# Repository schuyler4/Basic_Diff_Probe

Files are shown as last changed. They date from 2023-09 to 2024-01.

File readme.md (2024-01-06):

<h1> 
Basic Diff Probe 
</h1>
I need a differential probe, but I don't need particularly good specs. I don't need very high bandwidth or voltage. This is my solution. 

There are two revisions. The second revision is the same circuit board and circuit as the first revision. The only difference is a compensation
capacitor added in the feedback loop of the split supply buffer to get rid of some oscillation I was seeing.
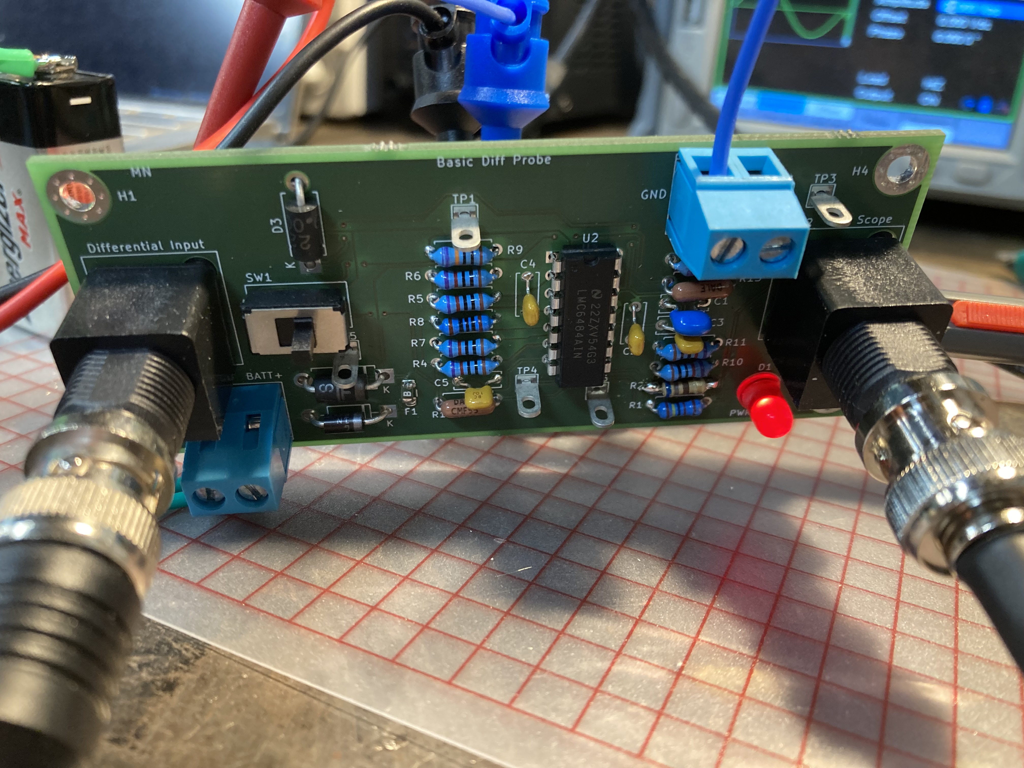
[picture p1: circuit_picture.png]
Circuit Picture


<h3> Specs </h3>
<ul>
<li> Power Supply: 9V Battery </li>
<li> Bandwidth: 20kHz (1x) / 200Hz (10x) </li>
<li> Offset < 2mV </li>
<li> Maximum Differential Input 10x (1x): 50V (5V) </li>
<li> Minimum Differential Input 10x (1x): -50V (-5V) </li>
<li> Maximum Single Ended Input 10x (1x): 25V (2.5V) </li>
<li> Minimum Differential Input 10x (1x): -25V (-2.5V) </li>
<li> Attenuation Options: 
<ul>
    <li> 10X </li>
    <li> 1X </li>
</ul>
</li>
</ul>
<h3> Example </h3>
Here is an example measurement taken of a sweep from my curve tracer. The purple trace is from the diff probe and the yellow trace is regular single ended oscilloscope measurement.    

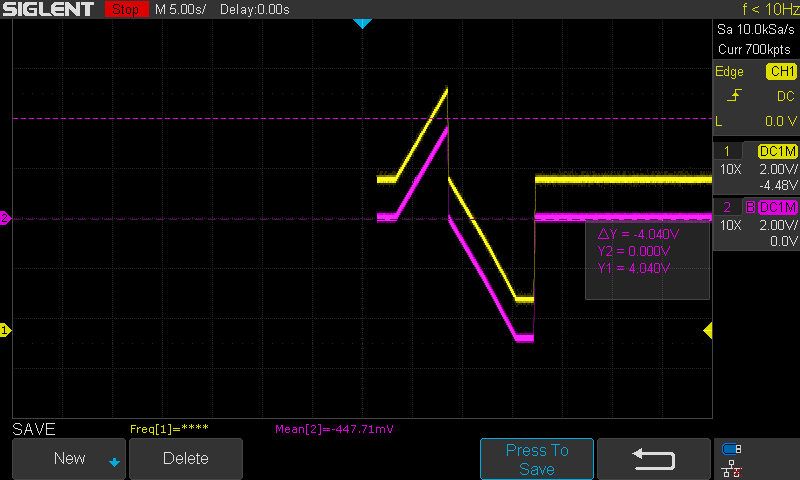
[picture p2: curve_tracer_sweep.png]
Trace


<h3> Possible Improvements </h3>
<ol>
<li> For some reason the bandwidth in 10x mode is very low. I'm not sure why this is. </li> 
<li> It is very hard to tell which mode the probe is in (10x or 1x) without looking at a known signal. </li>
</ol>
</p>

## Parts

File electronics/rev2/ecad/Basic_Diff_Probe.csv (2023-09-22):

Source: | C:\Users\marek\Documents\projects\Basic_Diff_Probe\ecad\Basic_Diff_Probe.kicad_sch
Date: | 9/8/2023 5:32:33 PM
Tool: | Eeschema 7.0.1
Generator: | C:\Program Files\KiCad\6.0\bin\scripting\plugins/bom_csv_grouped_by_value.py
Component Count: | 38
Individual Components:
Item | Qty | Reference(s) | Value | LibPart | Footprint | Datasheet
 |  | C1 | 10uF | Device:C | Capacitor_THT:C_Disc_D6.0mm_W2.5mm_P5.00mm | ~
 |  | C2 | 0.1uF | Device:C | Capacitor_THT:C_Disc_D6.0mm_W2.5mm_P5.00mm | ~
 |  | C3 | 0.1uF | Device:C | Capacitor_THT:C_Disc_D6.0mm_W2.5mm_P5.00mm | ~
 |  | C4 | 0.1uF | Device:C | Capacitor_THT:C_Disc_D6.0mm_W2.5mm_P5.00mm | ~
 |  | C5 | 10pF | Device:C | Capacitor_THT:C_Disc_D6.0mm_W2.5mm_P5.00mm | ~
 |  | D1 | WP7113ID | Device:LED | LED_THT:LED_D5.0mm | ~
 |  | D2 | SA10A | Device:D_Zener | Diode_THT:D_DO-15_P10.16mm_Horizontal | ~
 |  | D3 | SA9.0CA | Device:D_TVS | Diode_THT:D_DO-15_P10.16mm_Horizontal | ~
 |  | D4 | 1N5817 | Diode:1N5817 | Diode_THT:D_DO-41_SOD81_P10.16mm_Horizontal | http://www.vishay.com/docs/88525/1n5817.pdf
 |  | F1 | 100mA | Device:Fuse | Fuse:Fuse_1206_3216Metric_Pad1.42x1.75mm_HandSolder | ~
 |  | H1 | M3 | Mechanical:MountingHole_Pad | MountingHole:MountingHole_3.2mm_M3_Pad_Via | ~
 |  | H2 | M3 | Mechanical:MountingHole_Pad | MountingHole:MountingHole_3.2mm_M3_Pad_Via | ~
 |  | H3 | M3 | Mechanical:MountingHole_Pad | MountingHole:MountingHole_3.2mm_M3_Pad_Via | ~
 |  | H4 | M3 | Mechanical:MountingHole_Pad | MountingHole:MountingHole_3.2mm_M3_Pad_Via | ~
 |  | J1 | 9V Battery Input | Connector:Screw_Terminal_01x02 | TerminalBlock_Phoenix:TerminalBlock_Phoenix_MKDS-1,5-2-5.08_1x02_P5.08mm_Horizontal | ~
 |  | J2 | To Scope | Connector:Conn_Coaxial | Connector_Coaxial:BNC_Amphenol_031-5539_Vertical | ~
 |  | J3 | Differential Input | Connector:Conn_Coaxial | Connector_Coaxial:BNC_Amphenol_031-5539_Vertical | ~
 |  | R1 | 1.4k | Device:R_US | Resistor_THT:R_Axial_DIN0207_L6.3mm_D2.5mm_P7.62mm_Horizontal | ~
 |  | R2 | 0 | Device:R_US | Resistor_THT:R_Axial_DIN0207_L6.3mm_D2.5mm_P7.62mm_Horizontal | ~
 |  | R4 | 10k | Device:R_US | Resistor_THT:R_Axial_DIN0207_L6.3mm_D2.5mm_P7.62mm_Horizontal | ~
 |  | R5 | 10k | Device:R_US | Resistor_THT:R_Axial_DIN0207_L6.3mm_D2.5mm_P7.62mm_Horizontal | ~
 |  | R6 | 10k | Device:R_US | Resistor_THT:R_Axial_DIN0207_L6.3mm_D2.5mm_P7.62mm_Horizontal | ~
 |  | R7 | 10k | Device:R_US | Resistor_THT:R_Axial_DIN0207_L6.3mm_D2.5mm_P7.62mm_Horizontal | ~
 |  | R8 | 100 | Device:R_US | Resistor_THT:R_Axial_DIN0207_L6.3mm_D2.5mm_P7.62mm_Horizontal | ~
 |  | R9 | 100k | Device:R_US | Resistor_THT:R_Axial_DIN0207_L6.3mm_D2.5mm_P7.62mm_Horizontal | ~
 |  | R10 | 10k | Device:R_US | Resistor_THT:R_Axial_DIN0207_L6.3mm_D2.5mm_P7.62mm_Horizontal | ~
 |  | R11 | 10k | Device:R_US | Resistor_THT:R_Axial_DIN0207_L6.3mm_D2.5mm_P7.62mm_Horizontal | ~
 |  | R12 | 900k | Device:R_US | Resistor_THT:R_Axial_DIN0207_L6.3mm_D2.5mm_P7.62mm_Horizontal | ~
 |  | R13 | 900k | Device:R_US | Resistor_THT:R_Axial_DIN0207_L6.3mm_D2.5mm_P7.62mm_Horizontal | ~
 |  | R16 | 100k | Device:R_US | Resistor_THT:R_Axial_DIN0207_L6.3mm_D2.5mm_P7.62mm_Horizontal | ~
 |  | SW1 | EG2209A | Switch:SW_Push_DPDT | Diff_Probe_Parts:SW_EG2209A | ~
 |  | TP1 | TestPoint | Connector:TestPoint | TestPoint:TestPoint_Keystone_5000-5004_Miniature | ~
 |  | TP2 | TestPoint | Connector:TestPoint | TestPoint:TestPoint_Keystone_5000-5004_Miniature | ~
 |  | TP3 | TestPoint | Connector:TestPoint | TestPoint:TestPoint_Keystone_5000-5004_Miniature | ~
 |  | TP4 | TestPoint | Connector:TestPoint | TestPoint:TestPoint_Keystone_5000-5004_Miniature | ~
 |  | TP5 | TestPoint | Connector:TestPoint | TestPoint:TestPoint_Keystone_5000-5004_Miniature | ~
 |  | TP6 | TestPoint | Connector:TestPoint | TestPoint:TestPoint_Keystone_5000-5004_Miniature | ~
 |  | U2 | LMC6484AIN | Device:Opamp_Quad | Package_DIP:DIP-14_W7.62mm | ~
Collated Components:
Item | Qty | Reference(s) | Value | LibPart | Footprint | Datasheet
1 | 1 | C1 | 10uF | Device:C | Capacitor_THT:C_Disc_D6.0mm_W2.5mm_P5.00mm | ~
2 | 3 | C2, C3, C4 | 0.1uF | Device:C | Capacitor_THT:C_Disc_D6.0mm_W2.5mm_P5.00mm | ~
3 | 1 | C5 | 10pF | Device:C | Capacitor_THT:C_Disc_D6.0mm_W2.5mm_P5.00mm | ~
4 | 1 | D1 | WP7113ID | Device:LED | LED_THT:LED_D5.0mm | ~
5 | 1 | D2 | SA10A | Device:D_Zener | Diode_THT:D_DO-15_P10.16mm_Horizontal | ~
6 | 1 | D3 | SA9.0CA | Device:D_TVS | Diode_THT:D_DO-15_P10.16mm_Horizontal | ~
7 | 1 | D4 | 1N5817 | Diode:1N5817 | Diode_THT:D_DO-41_SOD81_P10.16mm_Horizontal | http://www.vishay.com/docs/88525/1n5817.pdf
8 | 1 | F1 | 100mA | Device:Fuse | Fuse:Fuse_1206_3216Metric_Pad1.42x1.75mm_HandSolder | ~
9 | 4 | H1, H2, H3, H4 | M3 | Mechanical:MountingHole_Pad | MountingHole:MountingHole_3.2mm_M3_Pad_Via | ~
10 | 1 | J1 | 9V Battery Input | Connector:Screw_Terminal_01x02 | TerminalBlock_Phoenix:TerminalBlock_Phoenix_MKDS-1,5-2-5.08_1x02_P5.08mm_Horizontal | ~
11 | 1 | J2 | To Scope | Connector:Conn_Coaxial | Connector_Coaxial:BNC_Amphenol_031-5539_Vertical | ~
12 | 1 | J3 | Differential Input | Connector:Conn_Coaxial | Connector_Coaxial:BNC_Amphenol_031-5539_Vertical | ~
13 | 1 | R1 | 1.4k | Device:R_US | Resistor_THT:R_Axial_DIN0207_L6.3mm_D2.5mm_P7.62mm_Horizontal | ~
14 | 1 | R2 | 0 | Device:R_US | Resistor_THT:R_Axial_DIN0207_L6.3mm_D2.5mm_P7.62mm_Horizontal | ~
15 | 6 | R4, R5, R6, R7, R10, R11 | 10k | Device:R_US | Resistor_THT:R_Axial_DIN0207_L6.3mm_D2.5mm_P7.62mm_Horizontal | ~
16 | 1 | R8 | 100 | Device:R_US | Resistor_THT:R_Axial_DIN0207_L6.3mm_D2.5mm_P7.62mm_Horizontal | ~
17 | 2 | R9, R16 | 100k | Device:R_US | Resistor_THT:R_Axial_DIN0207_L6.3mm_D2.5mm_P7.62mm_Horizontal | ~
18 | 2 | R12, R13 | 900k | Device:R_US | Resistor_THT:R_Axial_DIN0207_L6.3mm_D2.5mm_P7.62mm_Horizontal | ~
19 | 1 | SW1 | EG2209A | Switch:SW_Push_DPDT | Diff_Probe_Parts:SW_EG2209A | ~
20 | 6 | TP1, TP2, TP3, TP4, TP5, TP6 | TestPoint | Connector:TestPoint | TestPoint:TestPoint_Keystone_5000-5004_Miniature | ~
21 | 1 | U2 | LMC6484AIN | Device:Opamp_Quad | Package_DIP:DIP-14_W7.62mm | ~

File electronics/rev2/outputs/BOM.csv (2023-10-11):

Item | Qty | Reference(s) | Value | Part # | Distributor | Distributor Part # | Unit Price | Price | Carted
1 | 1 | C1 | 10uF | FG26X7R1E106KRT06 | DIGIKEY | 445-173437-1-ND | 0.67 | 0.67 | T
2 | 3 | C2, C3, C4 | 0.1uF | K104K10X7RF5UH5 | DIGIKEY | BC2665CT-ND | 0.23 | 0.69 | T
3 | 1 | C5 | 10pF | K100J15C0GF5TH5 | DIGIKEY | BC1030CT-ND | 0.27 | 0.27 | T
4 | 1 | D1 | WP7113ID | WP7113ID | DIGIKEY | 754-1264-ND | 0.1 | 0.1 | T
5 | 1 | D2 | SA10A | SA10A | DIGIKEY | SA10ALFCT-ND | 0.44 | 0.44 | T
6 | 1 | D3 | SA9.0CA | SA9.0CA | DIGIKEY | 18-SA9.0CACT-ND | 0.49 | 0.49 | T
7 | 1 | D4 | 1N5817 | 1N5817 | DIGIKEY | 497-4547-1-ND | 0.44 | 0.44 | T
8 | 1 | F1 | 100mA | 0466.125NR | DIGIKEY | F1450CT-ND | 0.91 | 0.91 | T
9 | 1 | J1 | 9V Battery Input | TB004-508-02BE | DIGIKEY | 102-6179-ND | 0.71 | 0.71 | T
10 | 1 | J2 | To Scope | 031-5539 | DIGIKEY | ARF2045-ND | 7.35 | 7.35 | T
11 | 1 | J3 | Differential Input | 031-5539 | DIGIKEY | ARF2045-ND | 7.35 | 7.35 | T
12 | 1 | R1 | 1.4k | MFR-25FBF52-1K4 | DIGIKEY | 1.40KXBK-ND | 0.1 | 0.1 | T
13 | 1 | R2 | 680 | CF14JT680RCT-ND | DIGIKEY | CF14JT680RCT-ND | 0.1 | 0.1 | T
14 | 6 | R4, R5, R6, R7, R10, R11 | 10k | YR1B10KCC | DIGIKEY | A105970CT-ND | 0.63 | 3.78 | T
15 | 1 | R8 | 100 | MFR-25FBF52-100R | DIGIKEY | 100XBK-ND | 0.1 | 0.1 | T
16 | 2 | R9, R16 | 100k | YR1B100KCC | DIGIKEY | A105968CT-ND | 0.63 | 1.26 | T
17 | 2 | R12, R13 | 900k | CMF55900K00BEBF | DIGIKEY | CMF55900K00BEBF-ND | 2.44 | 4.88 | T
18 | 1 | SW1 | EG2209A | EG2209A | DIGIKEY | EG1908-ND | 1.18 | 1.18 | T
19 | 6 | TP1, TP2, TP3, TP4, TP5, TP6 | TestPoint | 4952 | DIGIKEY | 36-4952-ND | 0.26 | 1.56 | T
20 | 1 | U2 | LMC6484AIN | LMC6484AIN/NOPB | DIGIKEY | LMC6484AIN/NOPB-ND | 3.18 | 3.18 | T
total: |  |  |  |  |  |  |  | 35.61

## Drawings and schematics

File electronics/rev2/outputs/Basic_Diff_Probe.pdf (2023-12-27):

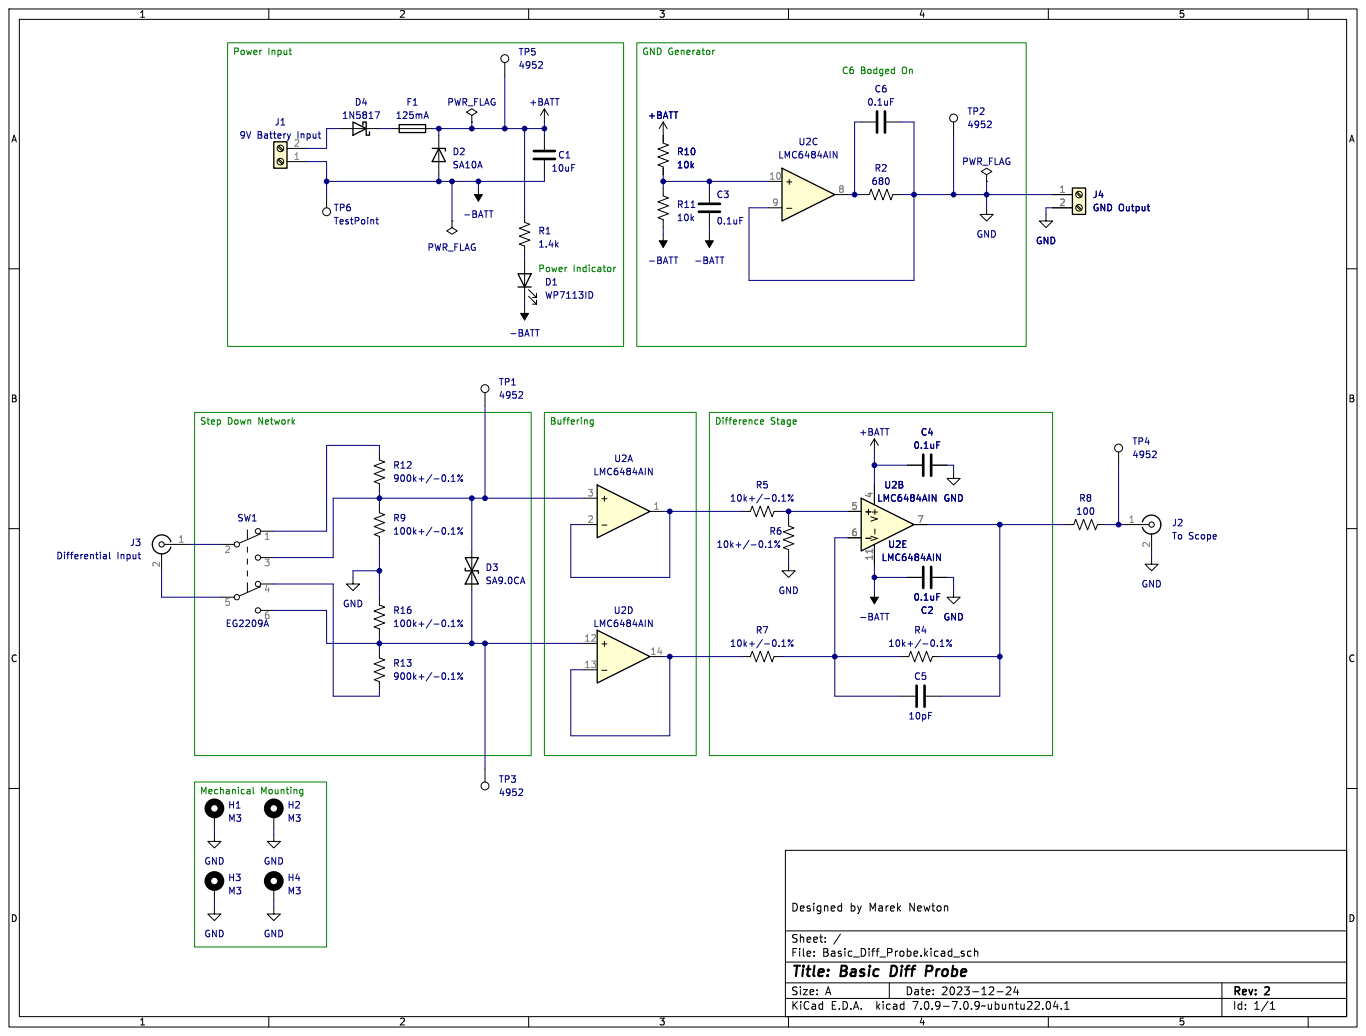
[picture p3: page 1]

Id: 1/1 Title: Basic Diff Probe

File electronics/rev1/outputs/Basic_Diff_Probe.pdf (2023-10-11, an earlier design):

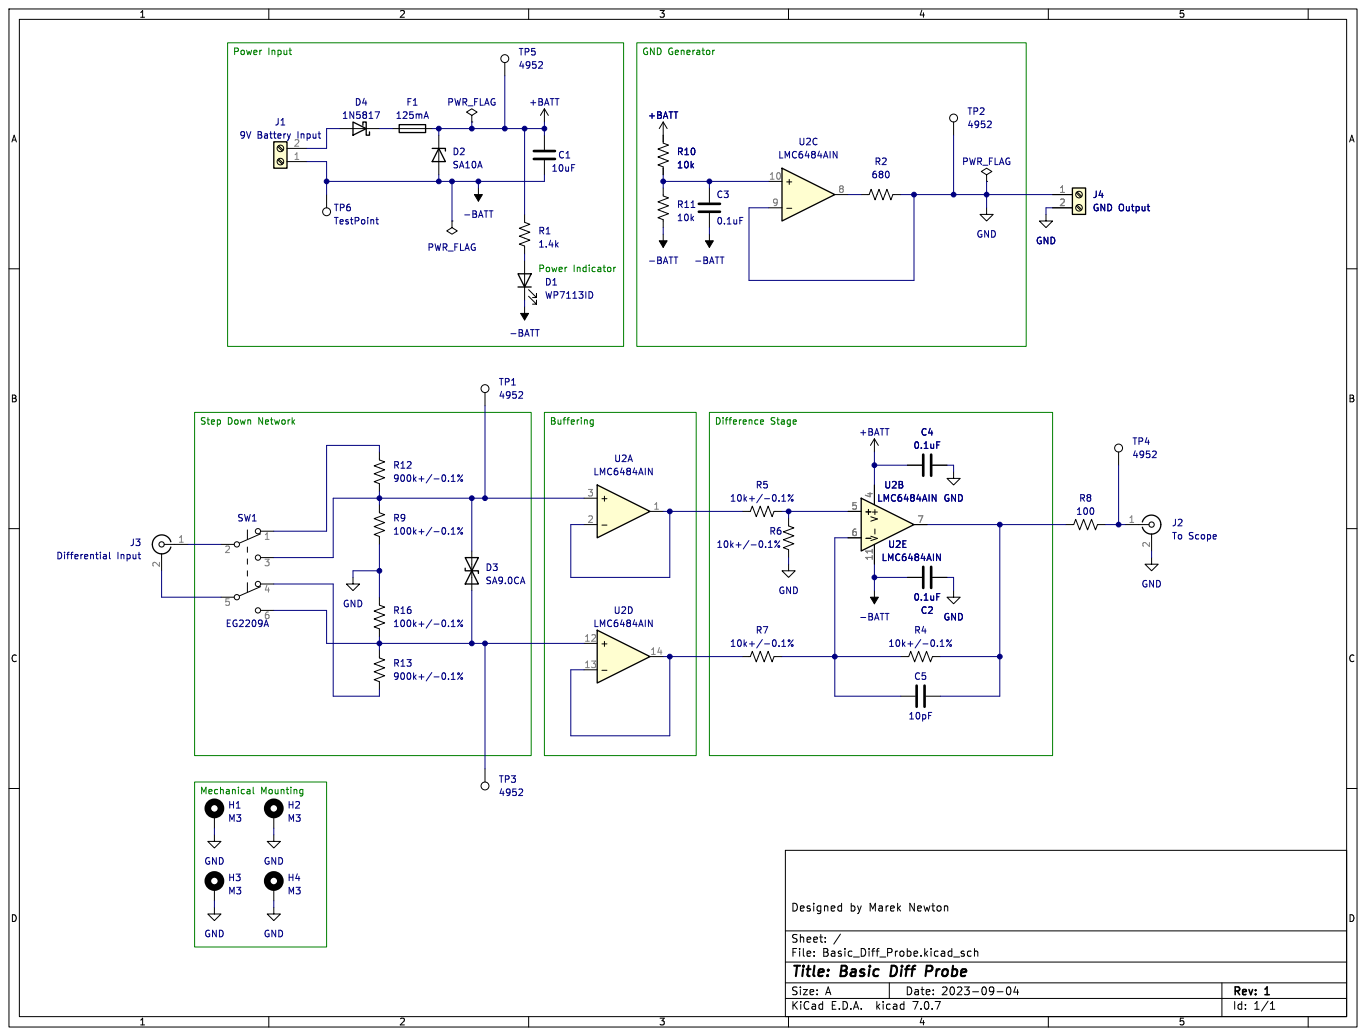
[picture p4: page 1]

Power Indicator Power Input

Id: 1/1 Title: Basic Diff Probe

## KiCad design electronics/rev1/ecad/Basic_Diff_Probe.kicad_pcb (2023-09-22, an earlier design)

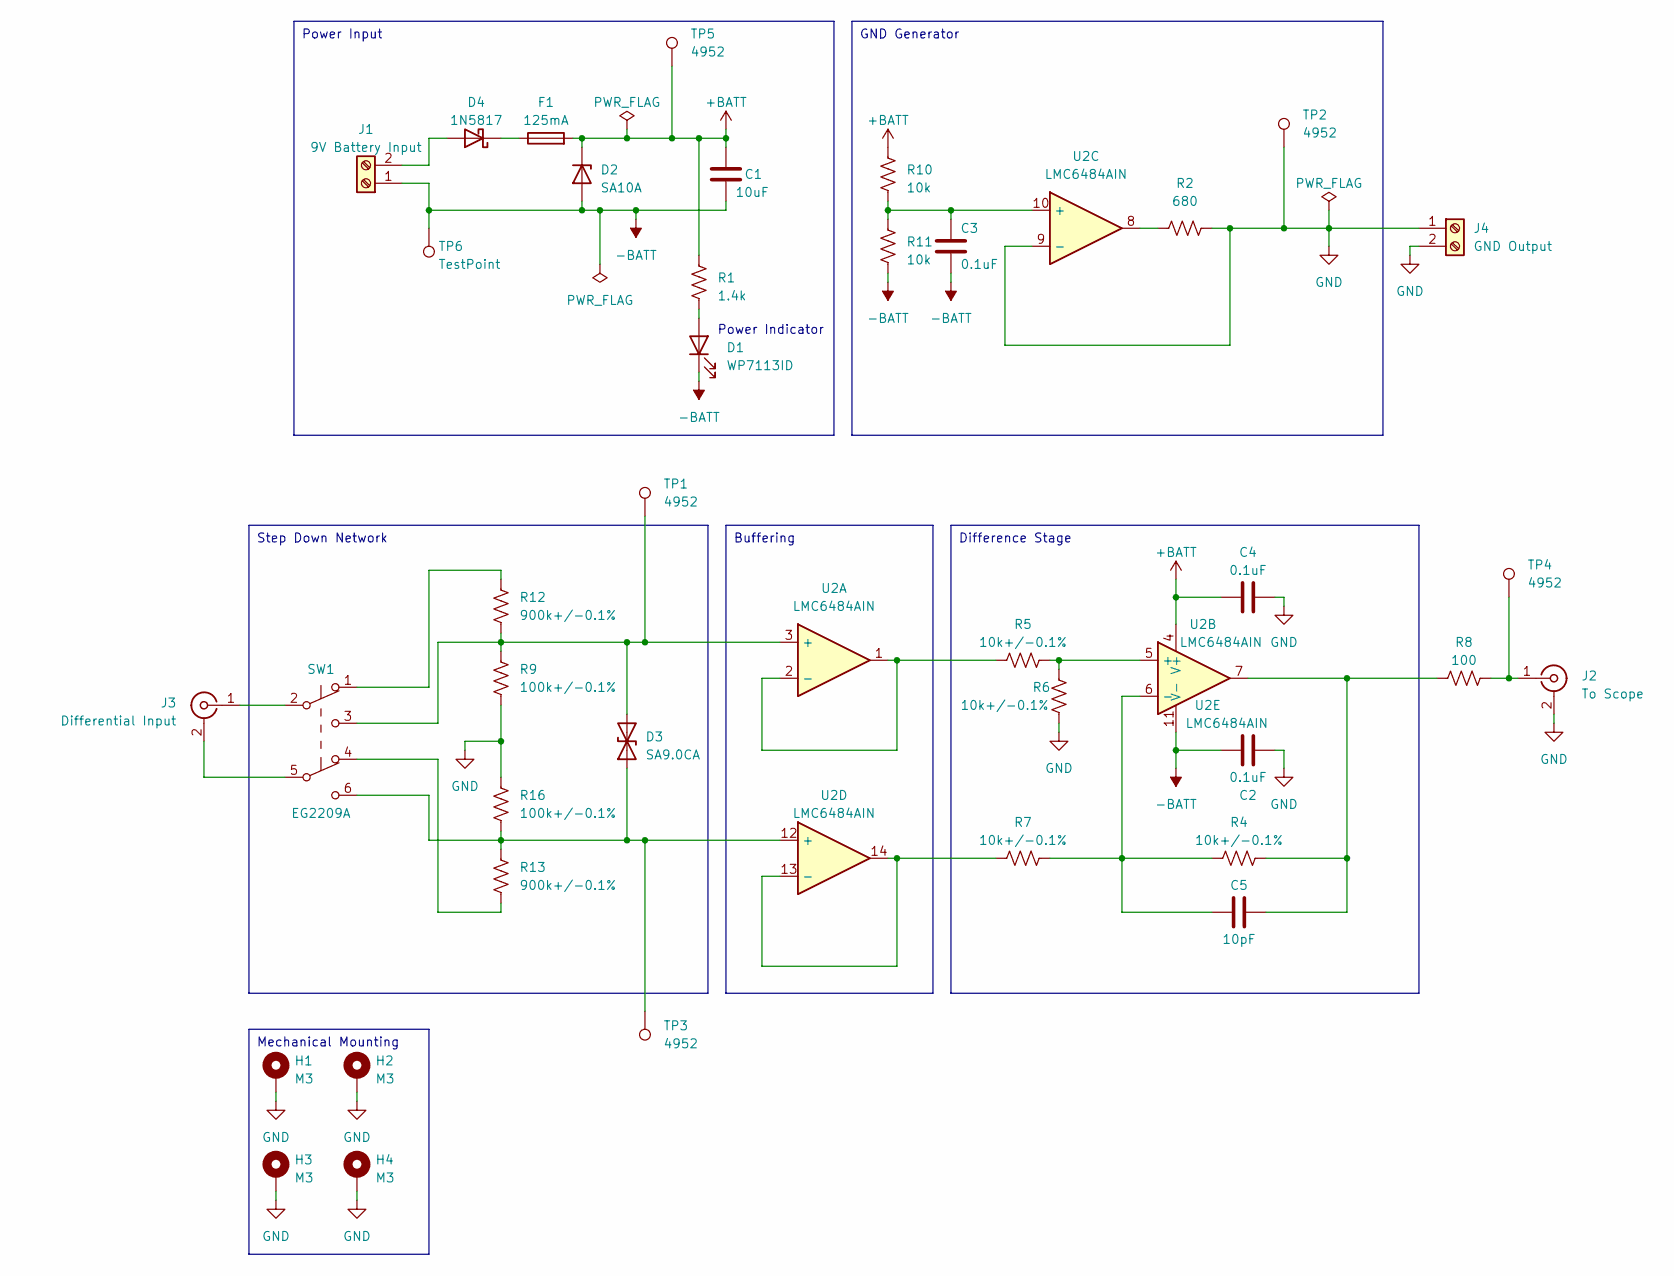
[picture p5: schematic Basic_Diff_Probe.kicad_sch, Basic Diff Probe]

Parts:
C1: 10uF; C_Disc_D6.0mm_W2.5mm_P5.00mm
C2, C3, C4: 0.1uF; C_Disc_D6.0mm_W2.5mm_P5.00mm
C5: 10pF; C_Disc_D6.0mm_W2.5mm_P5.00mm
D1: WP7113ID; LED_D5.0mm
D2: SA10A; D_DO-15_P10.16mm_Horizontal
D3: SA9.0CA; D_DO-15_P10.16mm_Horizontal
D4: 1N5817; D_DO-41_SOD81_P10.16mm_Horizontal
F1: 125mA; Fuse_1206_3216Metric_Pad1.42x1.75mm_HandSolder
H1, H2, H3, H4: M3; MountingHole_3.2mm_M3_Pad_Via
J1: 9V Battery Input; TerminalBlock_Phoenix_MKDS-1,5-2-5.08_1x02_P5.08mm_Horizont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
J2: To Scope; BNC_Amphenol_031-5539_Vertical
J3: Differential Input; BNC_Amphenol_031-5539_Vertical
J4: GND Output; TerminalBlock_Phoenix_MKDS-1,5-2-5.08_1x02_P5.08mm_Horizont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
R1: 1.4k; R_Axial_DIN0207_L6.3mm_D2.5mm_P7.62mm_Horizontal
R2: 680; R_Axial_DIN0207_L6.3mm_D2.5mm_P7.62mm_Horizontal
R4, R5, R6, R7: 10k+/-0.1%; R_Axial_DIN0207_L6.3mm_D2.5mm_P7.62mm_Horizontal
R8: 100; R_Axial_DIN0207_L6.3mm_D2.5mm_P7.62mm_Horizontal
R9, R16: 100k+/-0.1%; R_Axial_DIN0207_L6.3mm_D2.5mm_P7.62mm_Horizontal
R10, R11: 10k; R_Axial_DIN0207_L6.3mm_D2.5mm_P7.62mm_Horizontal
R12, R13: 900k+/-0.1%; R_Axial_DIN0207_L6.3mm_D2.5mm_P7.62mm_Horizontal
SW1: EG2209A; SW_EG2209A
TP1, TP2, TP3, TP4, TP5: 4952; TestPoint_THTPad_2.5x2.5mm_Drill1.2mm
TP6: TestPoint; TestPoint_THTPad_2.5x2.5mm_Drill1.2mm
U2: LMC6484AIN; DIP-14_W7.62mm

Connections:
+BATT: C1.1, C4.2, D2.1 (K), F1.2, R1.1, R10.1, TP5.1, U2.4 (V+)
-BATT: C1.2, C2.2, C3.2, D1.1 (K), D2.2 (A), J1.1, R11.2, TP6.1, U2.11 (V-)
GND: C2.1, C4.1, H1.1, H2.1, H3.1, H4.1, J2.2 (Ext), J4.1, J4.2, R2.2, R6.2, R9.2, R16.1, TP2.1, U2.9 (-)
unnamed: C5.2, R4.2, R8.1, U2.7
unnamed: D1.2 (A), R1.2
unnamed: D3.1 (A1), R13.1, R16.2, SW1.6 (C), TP3.1, U2.12 (+)
unnamed: D3.2 (A2), R9.1, R12.2, SW1.3 (C), TP1.1, U2.3 (+)
unnamed: D4.2 (A), J1.2
unnamed: D4.1 (K), F1.1
unnamed: J2.1 (In), R8.2, TP4.1
unnamed: J3.2 (Ext), SW1.5 (B)
unnamed: J3.1 (In), SW1.2 (B)
unnamed: R2.1, U2.8
unnamed: R12.1, SW1.1 (A)
unnamed: R13.2, SW1.4 (A)
unnamed: R5.1, U2.1, U2.2 (-)
unnamed: R5.2, R6.1, U2.5 (+)
unnamed: C5.1, R4.1, R7.2, U2.6 (-)
unnamed: C3.1, R10.2, R11.1, U2.10 (+)
unnamed: R7.1, U2.13 (-), U2.14

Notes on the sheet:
Buffering
GND Generator
Power Input
Step Down Network
Mechanical Mounting
Difference Stage
Power Indicator

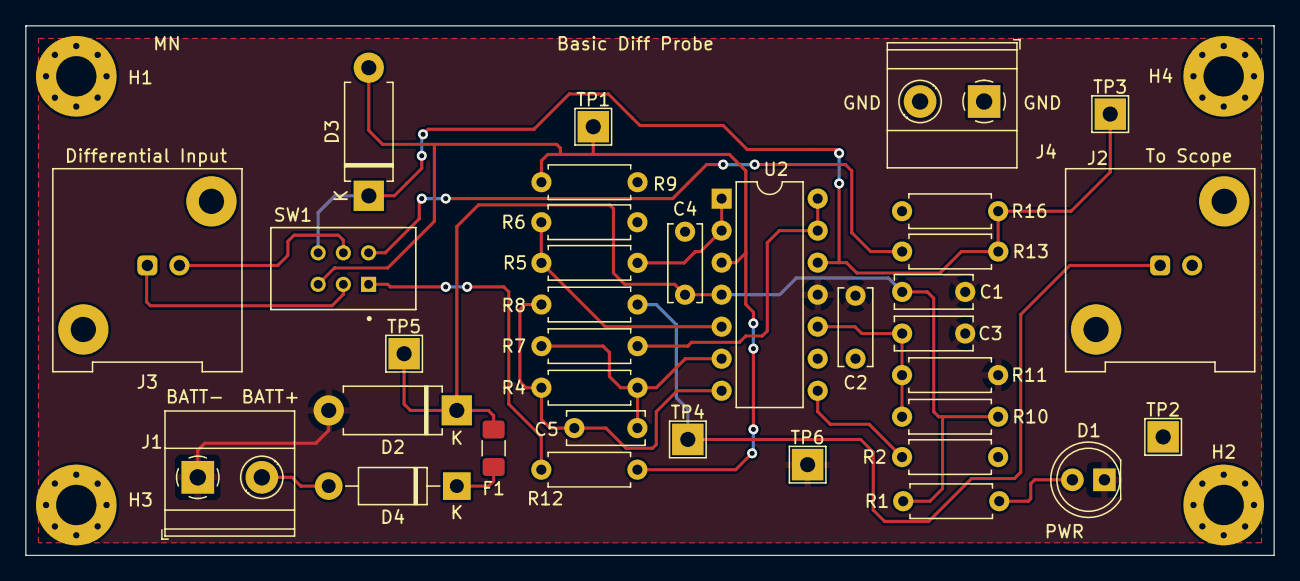
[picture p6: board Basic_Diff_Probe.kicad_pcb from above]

Board: 2 copper layers, 99.0 x 42.0 mm, 39 parts (0 on the bottom side), 20 nets.

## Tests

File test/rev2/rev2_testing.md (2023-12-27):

<h3>Accuracy Test</h3>
<p>
<b>Procedure:</b> Connect a function generator with a sine wave that has a frequency of 20kHz, and a peak voltage of 2.5Vp/10Vp. Connect the sine wave across the differential probe and a regular calibrated single ended scope probe. Make sure the diff probe ground is also connected. Look at both traces on the oscilloscope. Repeat for both 10x mode and 1x mode. If the diff probe sine wave is significantly distorted or attenuated decrees the frequency. This will find the bandwidth of the diff probe.
</p>

<b>Results:</b> The 1x trace is shown below:

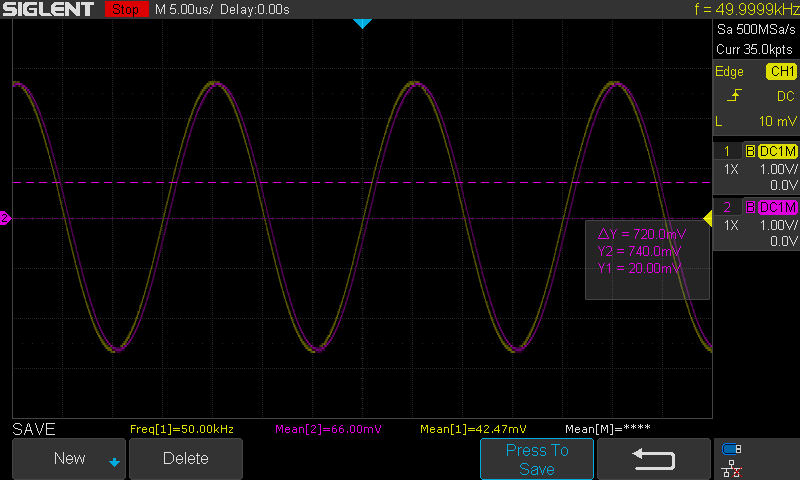
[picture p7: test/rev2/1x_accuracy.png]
1x Picture


And the 10x trace:

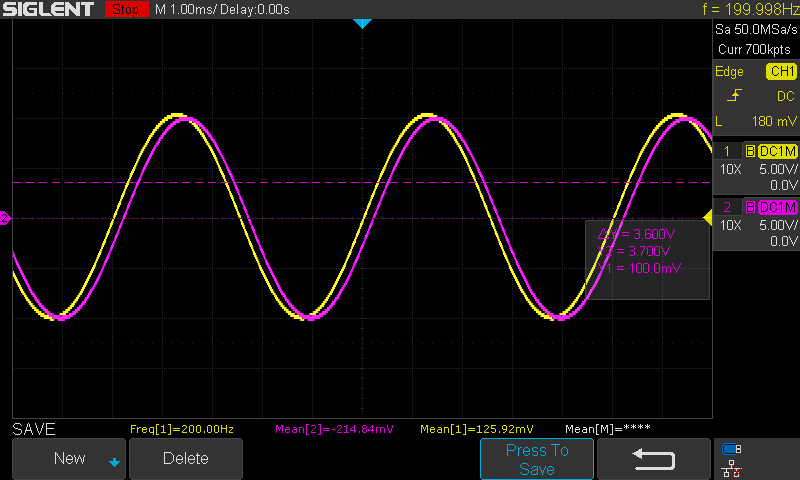
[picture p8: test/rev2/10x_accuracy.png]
10x Picture


<h3>Floating Voltage Test</h3>
<p>
<b>Procedure:</b> Connect an isolated power supply in series with a grounded power supply. Set the grounded power supply to 5V/0.5V. Connect the differential probe across the isolated floating power supply. Increase the floating power supply voltage to 20V in 5V steps. Measure and record the floating power supply with a DMM. Record the voltage measured with the diff probe. Check the accuracy with respect to the DMM. Reverse the diff probe leads so it reads a negative voltage and repeat the test. 
</p>
<p>
<b>Results:</b> 

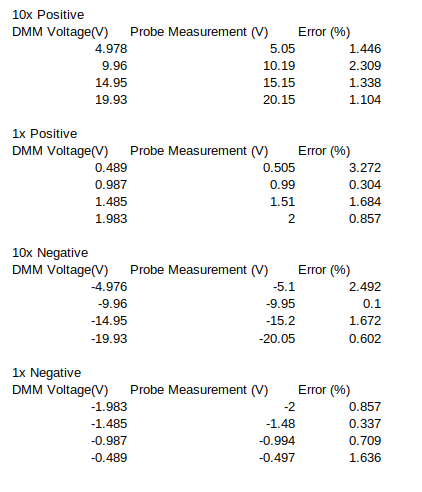
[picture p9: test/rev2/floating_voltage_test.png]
Floating Voltage Data

</p>

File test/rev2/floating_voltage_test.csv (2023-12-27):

10x Positive
DMM Voltage(V) | Probe Measurement (V) | Error (%)
4.978 | 5.05 | 1.446
9.96 | 10.19 | 2.309
14.95 | 15.15 | 1.338
19.93 | 20.15 | 1.104
1x Positive
DMM Voltage(V) | Probe Measurement (V) | Error (%)
0.489 | 0.505 | 3.272
0.987 | 0.99 | 0.304
1.485 | 1.51 | 1.684
1.983 | 2 | 0.857
10x Negative
DMM Voltage(V) | Probe Measurement (V) | Error (%)
-4.976 | -5.1 | 2.492
-9.96 | -9.95 | 0.1
-14.95 | -15.2 | 1.672
-19.93 | -20.05 | 0.602
1x Negative
DMM Voltage(V) | Probe Measurement (V) | Error (%)
-1.983 | -2 | 0.857
-1.485 | -1.48 | 0.337
-0.987 | -0.994 | 0.709
-0.489 | -0.497 | 1.636

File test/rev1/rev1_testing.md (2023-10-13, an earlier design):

<h3>Accuracy Test</h3>
<p>
<b>Procedure:</b> Connect a function generator with a sine wave that has a frequency of 20kHz, and a peak voltage of 2.5Vp/10Vp. Connect the sine wave across the differential probe and a regular calibrated single ended scope probe. Make sure the diff probe ground is also connected. Look at both traces on the oscilloscope. Repeat for both 10x mode and 1x mode. If the diff probe sine wave is significantly distorted or attenuated decrees the frequency. This will find the bandwidth of the diff probe.
</p>

<b>Results:</b> The 1x trace is shown below:

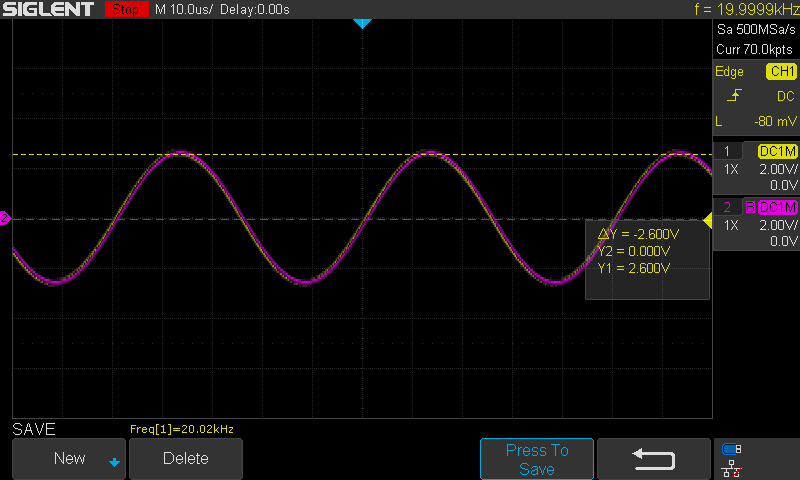
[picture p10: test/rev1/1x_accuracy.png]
1x Picture


And the 10x trace:

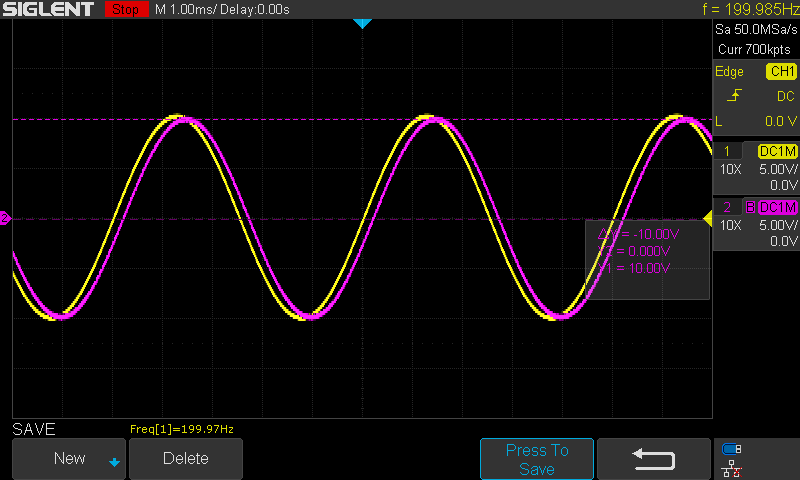
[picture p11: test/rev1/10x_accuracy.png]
10x Picture


<b> Analysis: </b> For some reason there was significant distortion and phase shift at frequencies higher than a few hundred Hz in 10x mode. Likewise in 1x with a few hundred kHz. I'm not exactly sure why this is as the bandwidth used should be significantly higher based on the gain bandwidth product of the op amp. 

<h3>Floating Voltage Test</h3>
<p>
<b>Procedure:</b> Connect an isolated power supply in series with a grounded power supply. Set the grounded power supply to 5V/0.5V. Connect the differential probe across the isolated floating power supply. Increase the floating power supply voltage to 20V in 5V steps. Measure and record the floating power supply with a DMM. Record the voltage measured with the diff probe. Check the accuracy with respect to the DMM. Reverse the diff probe leads so it reads a negative voltage and repeat the test. 
</p>
<p>
<b>Results:</b> 

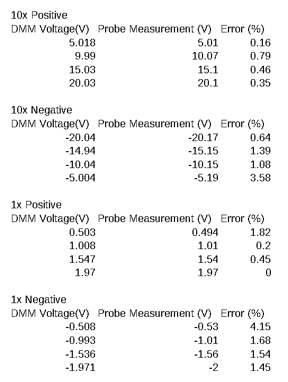
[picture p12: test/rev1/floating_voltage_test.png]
Floating Voltage Data

</p>

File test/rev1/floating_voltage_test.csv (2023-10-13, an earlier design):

10x Positive
DMM Voltage(V) | Probe Measurement (V) | Error (%)
5.018 | 5.01 | 0.16
9.99 | 10.07 | 0.79
15.03 | 15.1 | 0.46
20.03 | 20.1 | 0.35
10x Negative
DMM Voltage(V) | Probe Measurement (V) | Error (%)
-20.04 | -20.17 | 0.64
-14.94 | -15.15 | 1.39
-10.04 | -10.15 | 1.08
-5.004 | -5.19 | 3.58
1x Positive
DMM Voltage(V) | Probe Measurement (V) | Error (%)
0.503 | 0.494 | 1.82
1.008 | 1.01 | 0.2
1.547 | 1.54 | 0.45
1.97 | 1.97 | 0
1x Negative
DMM Voltage(V) | Probe Measurement (V) | Error (%)
-0.508 | -0.53 | 4.15
-0.993 | -1.01 | 1.68
-1.536 | -1.56 | 1.54
-1.971 | -2 | 1.45

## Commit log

2023-09-05 Start of schematic
    [Basic_Diff_Probe.kicad_pcb, Basic_Diff_Probe.kicad_sch]
2023-10-11 chage 0 to 680
    [BOM.csv, Basic_Diff_Probe.kicad_sch]
2023-10-12 test stuff
    [floating_voltage_test.csv]
2023-10-13 finished test writeup
    [floating_voltage_test.csv]
